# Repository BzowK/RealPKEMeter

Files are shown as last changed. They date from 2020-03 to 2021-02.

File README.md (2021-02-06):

# Real PKE Meter #

*This project is currently under development*

The goal of this project is to create a "working" PKE Meter (Ghostbusters) which is similar to the original's design however offers the below features:
## Features ##
- EMF Meter (LED Wings raise on stronger signal)
- Temperature & Humidity Readings
- Buzzer reflecting signal strength
- OLED display showing exact EMF reading, temperature, & humidity

Included *(& below)* is the initial breadboard layout which I'm currently testing.  The only addition I'm currently considering is a rocker switch to adjust sensitivity, however may try to add that via OLED screen.
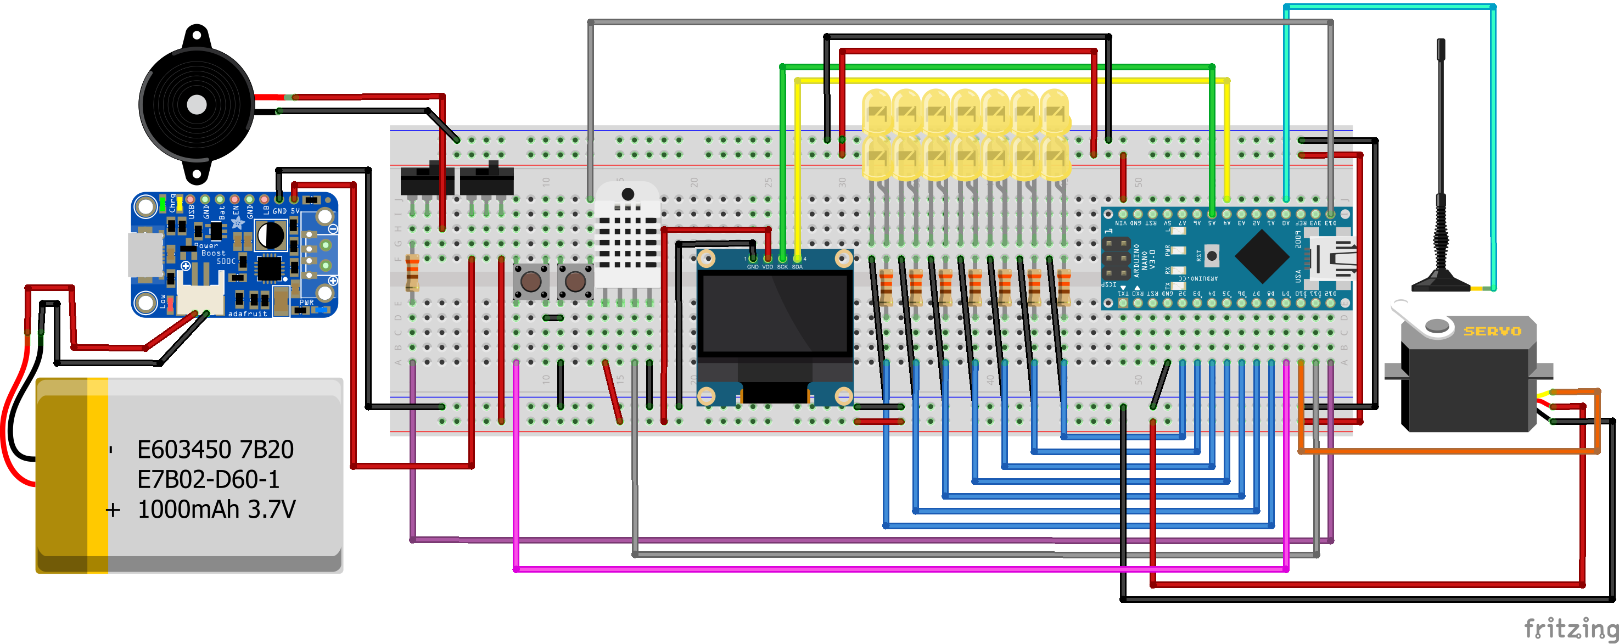
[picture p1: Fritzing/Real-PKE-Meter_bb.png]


## Current Status - 2/6/21 ##
- Cleaned up models a bit and added space for switch at bottom of handle
- Updated code so that...
	- EMF is much more accurate
	- LED now triggers via port directly thus freeing resources and making EMF readings more accurate
	- LED animation now similar to original PKE Meter from movie & flashes faster the higher the wings rise (higher field detected)
	- Rotary encoder code added
	- Misc smaller improvements & cleanup
	- Main thing lacking is OLED menu to configure sound, EMF sensitivity, etc.

***Note:** I've found that all the internal components interfere a bit with the EMF reader.  The best solution I've found so far is to wrap the ground wire, resistors, & wire going to A0 in aluminum foil then cover with heat shrink tubing - just until it gets outside unit.  Will document more when build guide updated.  Also seem to get better results using 3.3M resistance instead of initial 2.2M.*

## Old Updates ##
**10/20/20** - Finished prototype #1.  Didn't have time to get everything working the way I wanted, so finished it without a couple of features and with a couple of modifications so i could finish testing.  Below are lists of modifications made to finish first prototype plus changes planned for prototype #2 after testing...

**1st Prototype Modifications**

- Scaled model up 115% to ensure components & wiring fit *(Including modifying wings to use 5mm LEDs)*
- Optimized LED wiring
- Disabled rotary encoder
- Did not add menu / option selection on OLED
- Added physical switch to mute piezo speaker (since no menu option)
- Added 18650 battery case in handle

**Notes**

- The 1st prototype was printed in white I had abundance of then spray painted so apologies for rough look.  2nd prototype will use filament in correct color instead 
- The "Model/Modified-115_5mm" folder contains the 115% models with 5mm LEDs
- Placed switches after model print so had to cut space out for them manually

**Changes Currently Being Considered for Prototype #2**

*The #1 thing I've learned from the prototype is that despite the EMF code working as desired when testing on a breadboard without other components attached but same code, I get nowhere near the same result when assembled in prototype.  I'm assuming this is from interference from other components & power lines due to lack of shielding on antenna cable.*

- Find and implement shielding solution for EMF antenna 
- Integrate rotary encoder plus menu system to control audio, EMF sensitivity, scan rate, etc.
- LED animation - *Example: Have them scan top to bottom slowly and get faster depending on signal strength*
- Add external USB port for charging and/or Arduino programming
- Considering alternative power source with smaller footprint
- Clean up & fine-tune model for proper hardware mounting, switches, etc.

**6/3/20** - Have all main components working via script and am printing revised case so all components fit correctly. Just updated the Fritzing diagram as well as Arduino IDE script in repo.  Will upload STLs for case once finished, assembled, and tested.  Also decided to replace pair of buttons with a rotary encoder with push-button for more flexibility.  Pending tasks are below:

- Fine-tune EMF detection in script
- Integrate rotary encoder with push-button + menu options (mute, adjust sensitivity, etc)
- Finish updating case
Will post full build guide and files once finished.

**3/10/20** - I've tested individual components using source code which I combined into the final code (Real-PKE-Meter.ino).  All that's left is to test individual components using final code, program OLED display as desired, then fit into model.  Model files are currently copies of [CountDeMonet's project](https://github.com/CountDeMonet/Arduino_PKE_Meter), but will probably have to modify due to added components.

## Parts ##
*Links to exact parts used will be posted once prototype is complete*

- x1 Arduino Nano
- x1 DHT22 Sensor
- x1 SG90S Servo
- x14 3mm LEDs (20ma)
- x1 Piezo Speaker
- x1 0.96" OLED Display
- x9 330ohm Resistors
- x3 1M Resistors
- x1 Rotary Encoder /w Push Button
- x1 SPDT Toggle Switch
- x1 Powerboost 500
- x1 18650 Battery
- 3D printed parts
- Wiring
- Custom PCB *(Optional - Will post if one is made)*

***The build guide will be updated in detail after finishing 2nd prototype***

## Credit ##
This project is inspired by CountDeMonet's [Arduino_PKE_Meter](https://github.com/CountDeMonet/Arduino_PKE_Meter) which includes an OLED and LED wings, however was designed as a toy as all feedback is pre-programmed to occur with button presses and does not include sensors.

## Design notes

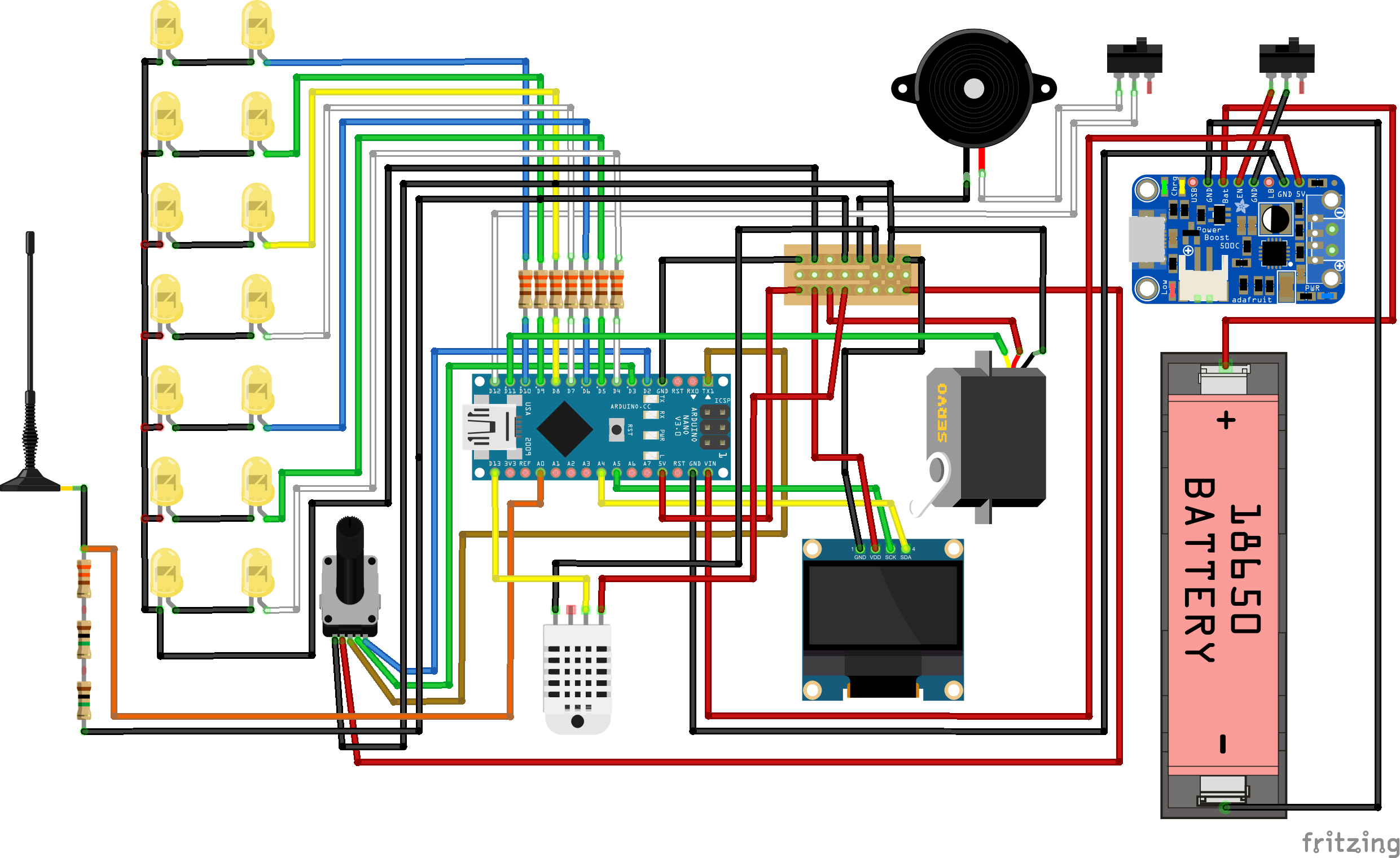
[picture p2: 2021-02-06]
Fritzing/Real_PKE_Diagram_bb.png

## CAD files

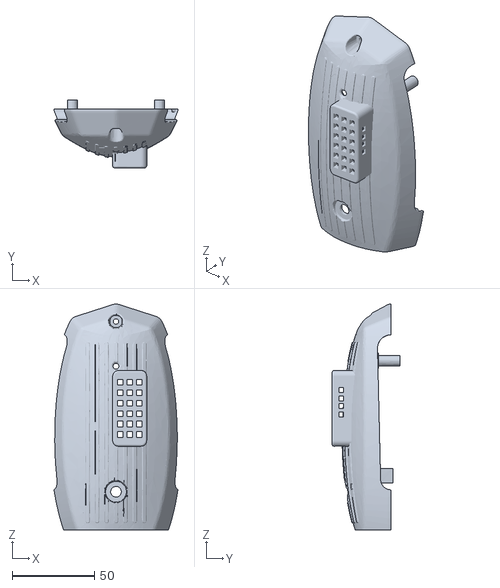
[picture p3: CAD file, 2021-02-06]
Model/Modified-115_5mm/Real PKE - Top_Rear.stl
75.3 x 41.2 x 137.3

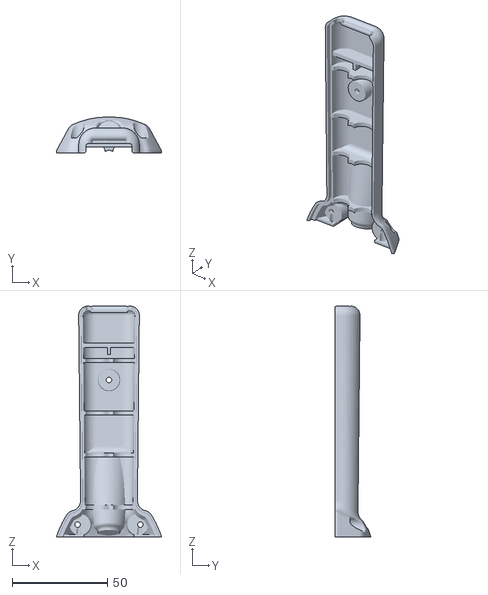
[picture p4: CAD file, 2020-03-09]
Model/Original/back_bottom.stl
55.3 x 18.9 x 121.2

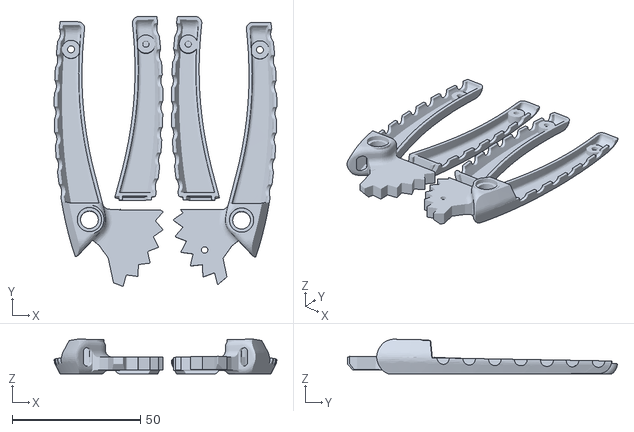
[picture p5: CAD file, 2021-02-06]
Model/Modified-115_5mm/Real PKE- Wings.stl
86.8 x 105.2 x 13.5

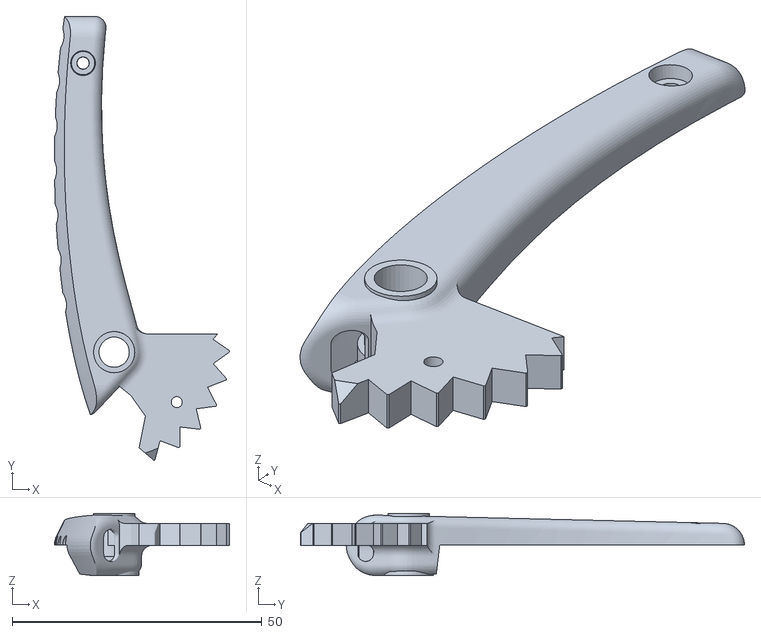
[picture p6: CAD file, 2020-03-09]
Model/Original/wings_left.stl
35.1 x 88.8 x 12.4

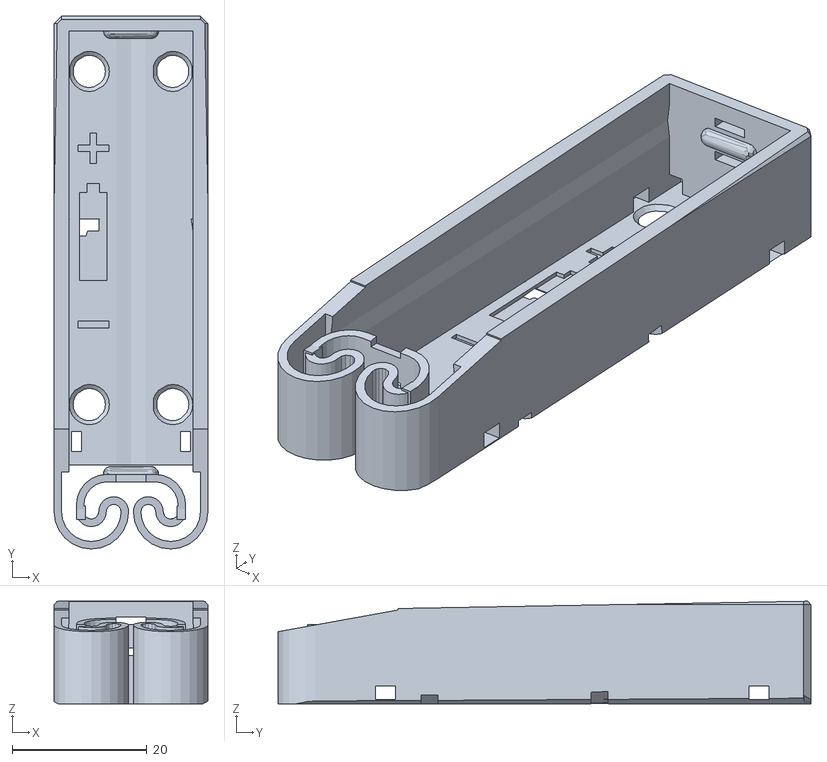
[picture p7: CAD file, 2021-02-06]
Model/Modified-115_5mm/Real PKE - BatCase.stl
22.9 x 79.2 x 15.2

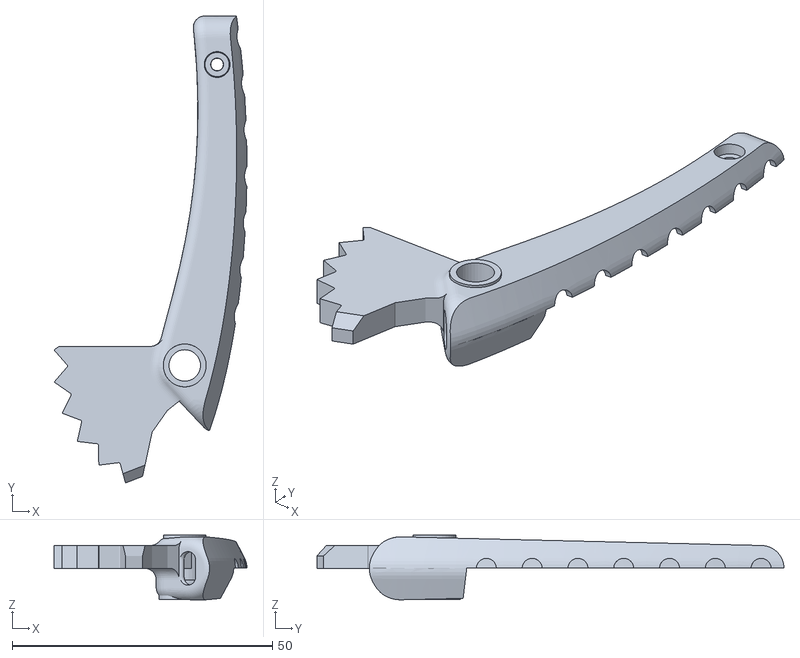
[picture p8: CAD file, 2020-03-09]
Model/Original/wings_right.stl
37.1 x 89.8 x 12.4

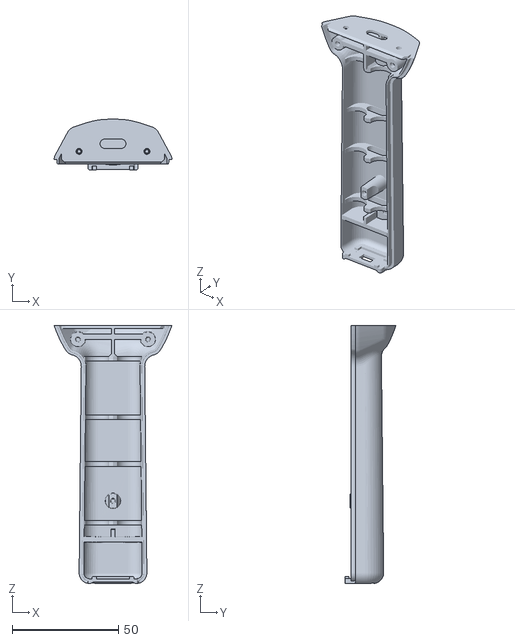
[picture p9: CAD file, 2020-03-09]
Model/Original/front_bottom.stl
55.3 x 23.9 x 121.2

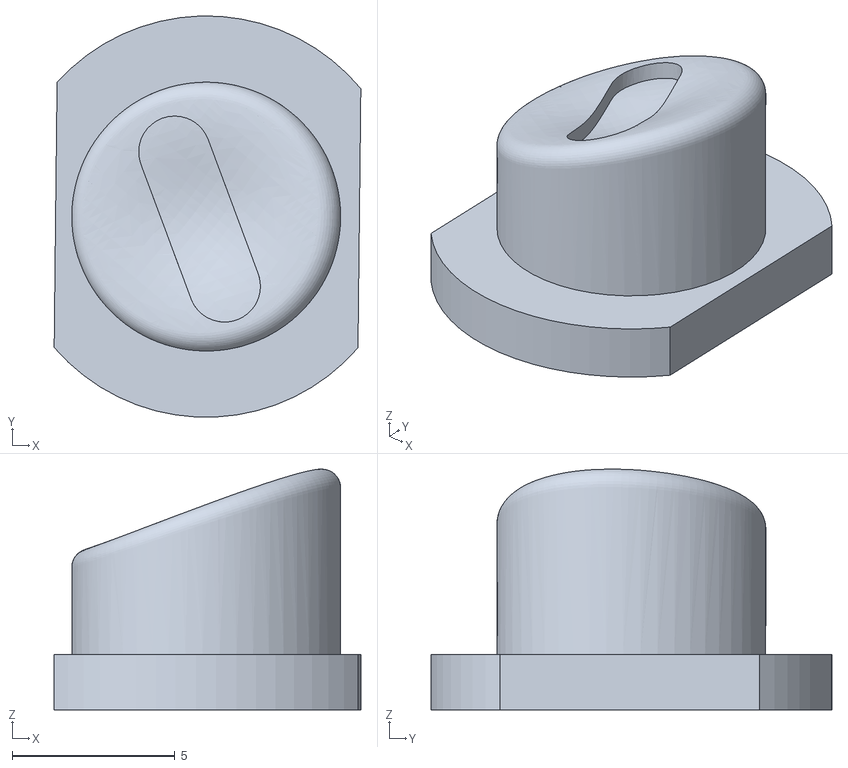
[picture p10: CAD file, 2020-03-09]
Model/Original/buttons_filled.stl
9.41 x 12.3 x 7.39

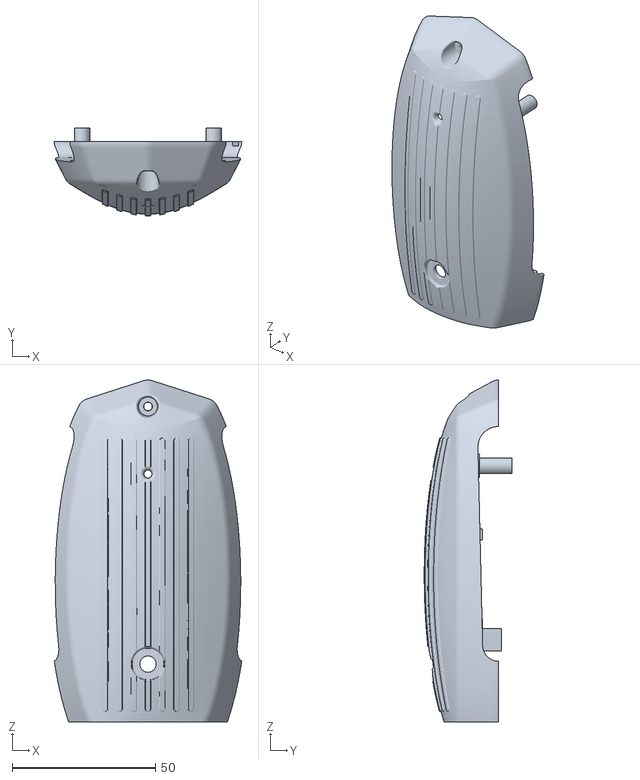
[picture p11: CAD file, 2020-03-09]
Model/Original/back_top.stl
65.5 x 30.6 x 119.4

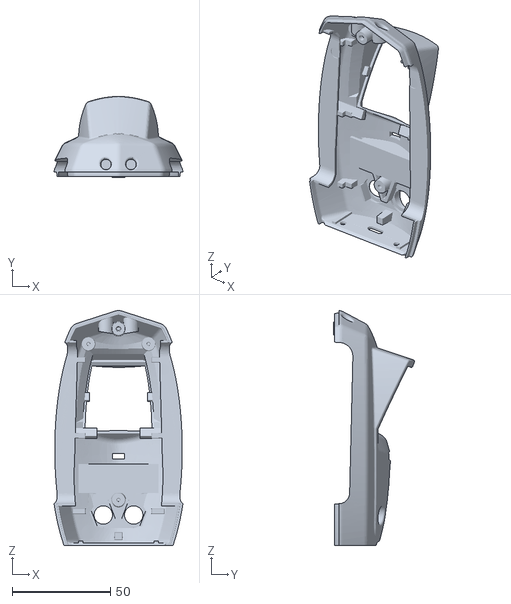
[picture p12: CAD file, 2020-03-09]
Model/Original/front_top.stl
65.5 x 41.3 x 119.4

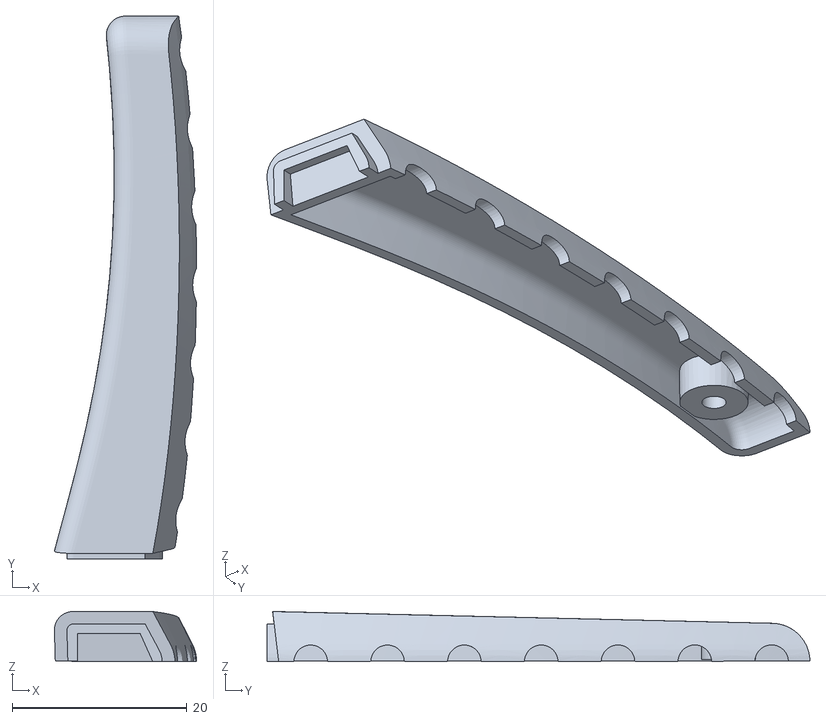
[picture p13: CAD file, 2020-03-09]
Model/Original/wings_cover_left.stl
16.3 x 62.2 x 5.74

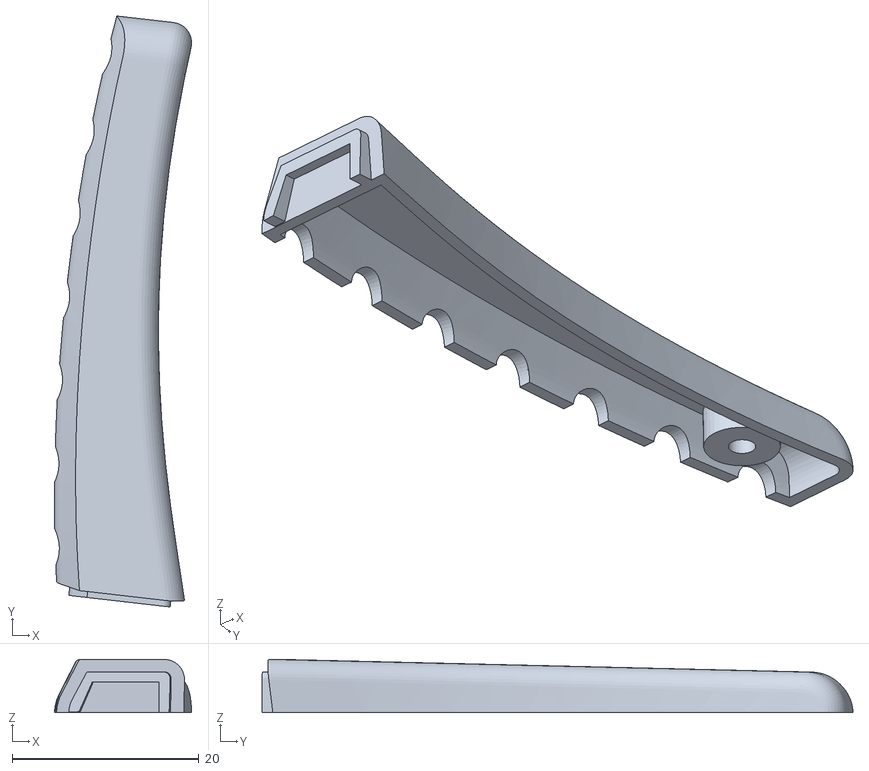
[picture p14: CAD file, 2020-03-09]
Model/Original/wings_cover_right.stl
14.7 x 63.3 x 5.71

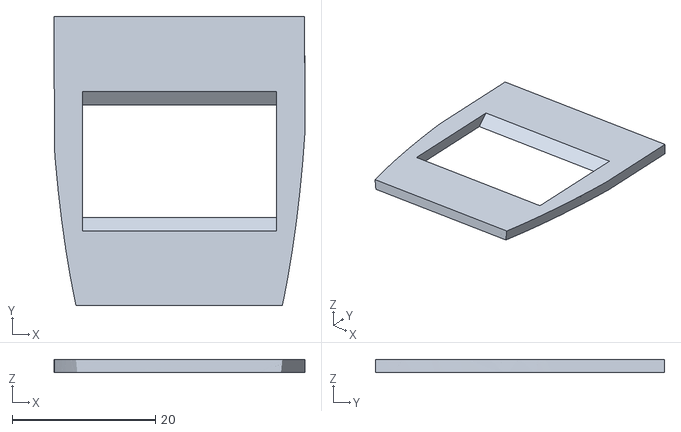
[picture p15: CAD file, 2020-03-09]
Model/Original/screen_holder.stl
35.0 x 40.3 x 1.86

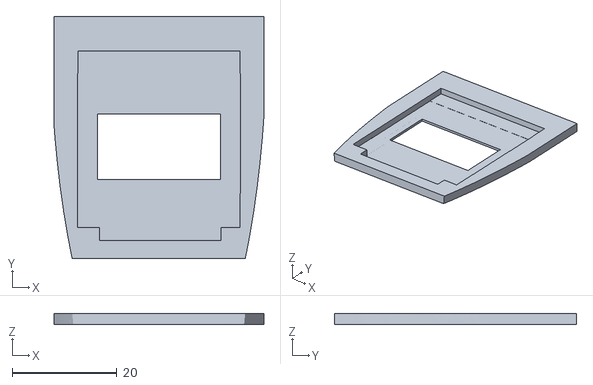
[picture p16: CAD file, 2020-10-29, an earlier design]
Model/Modified-115_5mm (Old)/Faceplate.stl
40.2 x 46.4 x 2.14

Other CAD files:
Model/Modified-115_5mm (Old)/TopRear.stl
Model/Modified-115_5mm (Old)/BatteryInsert.stl
Model/Modified-115_5mm (Old)/BottomFront.stl
Model/Modified-115_5mm (Old)/WingTops.stl
Model/Modified-115_5mm (Old)/BottomRear.stl
Model/Modified-115_5mm (Old)/Wing1.stl
Model/Modified-115_5mm (Old)/Wing2.stl

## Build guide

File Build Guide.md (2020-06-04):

# Real PKE Meter: Build Guide #

*This guide is currently under development*

## What You'll Need ##
**Parts**

Below are the exact parts I used.  Some may be substituted as desired, but code may need to be altered for them to work properly.

- x1 Arduino Nano *(Without headers preinstalled)*
- x1 DHT22 Sensor
- x1 SG90S Servo
- x14 3mm LEDs (20ma)
- x1 Piezo Speaker
- x1 0.96" OLED Display
- x2 330ohm Resistors
- x2 1M Resistors
- x1 Rotary Encoder /w Push Button
- x1 SPDT Toggle Switch
- x1 Powerboost 500 *(Without headers or ports  preinstalled)*
- x1 18650 Battery
- 3D printed parts
- 24 gauge wiring *(or stripped CAT5/CAT6 cable)*
- 22 gauge wiring *(optional?)*
- Shrink tubing

**Tools**

- 3D Printer *(or can order parts)*
- Soldering iron / solder
- Wire clippers / strippers
- Calipers or other measuring device *(Although I am located in the USA, this guide uses metric)*

## Important Notes ##

- I opted to not use a perfboard or custom PCB, but may design & add one in the future

- It is suggested (although not necessary) to test all components with code on a breadboard prior to assembly - especially if substituting parts.

# Procedure #
## Preparation ##
**1. Print or Order Parts**

**2. Prepare Hardware**

- Test on breadboard prior to assembly *(Optional)*
- Ensure all headers are removed to save space
- For each LED, trim the anode *(longer, positive)* down to ~4mm and trim the cathode *(shorter, negative)* down to ~5mm,  Once done, bend the anode at the base of the LED 90 degrees.  Bend the cathode 180 degrees to form a "U".

**3. Prepare Wiring**

Cut the wire lengths listed below...

*I used 22 gauge for everthing except where noted so that things fit correctly.  Noted colors do not matter & are used to keep straight their intention*

**LEDs**

- Cut x14 150mm *(24 gauge)* wires.  Solder one end of each to the 90 degree bent anode end of each of the 14 LEDs.
- Cut x2 200mm wires.  Strip 60mm off one end leaving that much base wire showing 

**Battery / Power**

 - x1 200mm Red
 -  

Using some of the above wires, solder the noted resistor inline between each noted pair - each resulting in a single cable.

## Assembly ##
**LEDs / Wings**

1. String the wire of each of the 7 LEDs though the upper part of the wing
2. Super glue each LED in place
3. Run the bare end of the 200mm through the wing and thread it through the "U" of each of the LEDs
4. Apply a bit of solder on each of the "U" connections

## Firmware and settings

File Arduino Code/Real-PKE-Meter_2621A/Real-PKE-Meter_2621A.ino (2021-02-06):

/*
Real PKE Meter
Revised 2/6/21 - BzowK

New / Fixed:
- Replaced digitalWrite with direct port for faster processing
- Improved EMF detection
- Added rotary encoder /w button support
 
ToDo:
- Add menu options to adjust sound & sensitivity
- OLED Settings Menu
  - Sound On/Off
  - EMF Sensitivity
  - ...

Pin Assignments:
- VIN - 5V
- GND - Ground
- A0 - Probe / Antenna
- A4 - SDA on Display
- A5 - SLC on Display
- D1 - Rotary Button
- D2 - Rotary CLK
- D3 - Rotary DT
- D4 - LED pair #1
- D5 - LED pair #2
- D6 - LED pair #3
- D7 - LED pair #4
- D8 - LED pair #5
- D9 - LED pair #6
- D10 - LED pair #7
- D11 - Servo Signal
- D12 - Piezo Buzzer
- D13 - DHT22
*/

//Libraries
  #include <Wire.h>
  #include <Adafruit_GFX.h>
  #include <Adafruit_SSD1306.h>
  #include <Servo.h>
  #include <DHT.h>
  #define DHTPIN 13
  #define DHTTYPE DHT22
  #define NUMREADINGS 15
  #define OLED_RESET 10
  #define SCREEN_WIDTH 128
  #define SCREEN_HEIGHT 64
  #define encoder0PinA  2
  #define encoder0PinB  3
  #define encoderButton 1
  Adafruit_SSD1306 display(SCREEN_WIDTH, SCREEN_HEIGHT, &Wire, -1);

// Init Servo
  Servo servo;

// Init DHT22
  DHT dht(DHTPIN, DHTTYPE);

// Init EMF
  int senseLimit = 15; // raise this number to decrease sensitivity (up to 1023 max)
  int probePin = 0;
  int val = 0;

// Init EMF Smoothing
  int readings[NUMREADINGS];
  int index = 0;
  int total = 0;
  int average = 0; 
  int turn_time = 100;
  int servoVal = 0;

// Init LED
  const int LED1 = 4;
  const int LED2 = 5;
  const int LED3 = 6;
  const int LED4 = 7;
  const int LED5 = 8;
  const int LED6 = 9;
  const int LED7 = 10;

// Init Buzzer
  int speakerPin = 12;
  int buzzer = 12;
  int buzzerTone = 0;

// Init Rotary Encoder
  byte clk;
  byte dir = 0;
  volatile unsigned int encoder0Pos = 0;

void setup() {

// Setup Serial
  Serial.begin(115200);

// Setup EMF Smoothing 
  for (int i = 0; i < NUMREADINGS; i++)
    readings[i] = 0;

// Setup DHT22
  dht.begin();

// Setup Servo
  servo.attach(11);
  servo.write(110);
    
// Setup LEDs
  pinMode(4, OUTPUT);
  pinMode(5, OUTPUT);
  pinMode(6, OUTPUT);
  pinMode(7, OUTPUT);
  pinMode(8, OUTPUT);
  pinMode(9, OUTPUT);
  pinMode(10, OUTPUT);

// Setup Speaker
  pinMode(speakerPin, OUTPUT);

// Setup OLED
  if(!display.begin(SSD1306_SWITCHCAPVCC, 0x3C)) {
    Serial.println(F("SSD1306 allocation failed"));
    for(;;);
  }
  delay(2000);
  display.clearDisplay();
  display.setTextColor(WHITE); 

 // Setup Rotary Encoder
  pinMode(encoder0PinA, INPUT);
  digitalWrite(encoder0PinA, HIGH);
  pinMode(encoder0PinB, INPUT);
  digitalWrite(encoder0PinB, HIGH);
  pinMode(encoderButton, INPUT);
  digitalWrite(encoderButton, HIGH);
  attachInterrupt(0, doEncoder, CHANGE);
  }

void loop() {

//Loop EMF
  val = analogRead(probePin);
  if(val >= 1){
    val = constrain(val, 1, senseLimit); 
    val = map(val, 1, senseLimit, 1, 1023); 
    total -= readings[index];
    readings[index] = val;
    total += readings[index];
    index = (index + 1);
    if (index >= NUMREADINGS)
      index = 0;
    average = total / NUMREADINGS;
    servoVal = map(average, 0, 1023, 110, 40);
    turn_time = map(average, 0, 1023, 200, 5);
    
// Loop LEDs
  LEDPattern();

// Loop Servo  
  AdServo();

// Write to Console for Testing & Calibrating
  Serial.println("val:");
  Serial.println(val);
  Serial.println("average:");
  Serial.println(average);
  Serial.print("turn_time: ");
  Serial.println(turn_time);
  Serial.print("ServoVal: ");
  Serial.println(servoVal);
  }

// Loop Speaker
  if (average > 0)
    tone(speakerPin, average / 3);
  else
    noTone(speakerPin);

// Loop DHT22
  float f = dht.readTemperature(true);
  float h = dht.readHumidity();
  if (isnan(h) || isnan(f)) {
  Serial.println("Failed to read from DHT sensor!");
  }
  display.clearDisplay();
  display.setTextSize(1);
  display.setCursor(22, 5);
  
// Loop OLED
  // Static Title
    display.println("Real PKE Meter");

  // Display Temperature
    display.setTextSize(1);
    display.setCursor(0,20);
    display.print("Temperature: ");
    display.print(f);
    display.print(" ");
    display.setTextSize(1);
    display.cp437(true);
    display.write(167);
    display.print("F");

  // Display Humidity
    display.setTextSize(1);
    display.setCursor(12, 30);
    display.print("Humidity: ");
    display.print(h);
    display.print(" %"); 

  // Display EMF Strength Value
    display.setTextSize(1);
    display.setCursor(15, 40);
    display.print("EMF Strength: ");
    display.print(average);
    display.display();

// Loop Rotary Encoder
  clk = digitalRead(encoderButton);
  }

void LEDPattern () {
  PORTD |= (1 << PD4);
  delay(turn_time);
  PORTD &= ~(1 << PD4);
  delay(turn_time);
  PORTD |= (1 << PD6);
  delay(turn_time);
  PORTD &= ~(1 << PD6);
  delay(turn_time);
  PORTB |= (1 << PB0);
  delay(turn_time);
  PORTB &= ~(1 << PB0);
  delay(turn_time);
  PORTB |= (1 << PB2);
  delay(turn_time);
  PORTB &= ~(1 << PB2);
  delay(turn_time);
  PORTB |= (1 << PB1);
  delay(turn_time);
  PORTB &= ~(1 << PB1);
  delay(turn_time);
  PORTD |= (1 << PD7);
  delay(turn_time);
  PORTD &= ~(1 << PD7);
  delay(turn_time);
  PORTD |= (1 << PD5);
  delay(turn_time);
  PORTD &= ~(1 << PD5);
  }

void AdServo () {
  servo.write(servoVal);
  }

void doEncoder() {
  if (digitalRead(encoder0PinA) == HIGH) {
    if (digitalRead(encoder0PinB) == LOW && encoder0Pos > 0) {
      encoder0Pos = encoder0Pos - 1;
      dir = 0;
    }
    else {
      encoder0Pos = encoder0Pos + 1;
      dir = 1;
    }
  }
  else
  {
    if (digitalRead(encoder0PinB) == LOW ) {
      encoder0Pos = encoder0Pos + 1;
      dir = 1;
    }
    else {
      if (encoder0Pos > 0) {
        encoder0Pos = encoder0Pos - 1;
        dir = 0;
      }
    }
  }
}

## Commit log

2020-06-04 Updates applied
    [Real-PKE_6-2-20.fzz, Real_PKE_Diagram.fzz]
2020-06-04 Rerouted wire
    [Real_PKE_Diagram.fzz]
2020-10-29 Updated 10-29-20
    Updated 10-29-20
    [BatteryInsert.stl, BottomFront.stl, BottomRear.stl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]
2020-10-29 Updated 10/29/20
    [BatteryInsert.stl, BottomFront.stl, BottomRear.stl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]
2021-02-06 Updated 2/6/21
    [BatteryInsert.stl, BottomFront.stl, BottomRear.stl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]
